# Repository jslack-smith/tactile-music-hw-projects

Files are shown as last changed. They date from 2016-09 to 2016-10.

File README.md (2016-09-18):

# tactile-music-hw-projects
Tactile Music is a project for an electrical engineering design course, ELEC3117, at UNSW.
This repo is for EAGLE project files.

How to use:
* clone this repo into your EAGLE projects folder

Notes:
* Use the DINA4_L (A4, landscape) frame on all sheets
* Use R-US_R0805 for resistors
* Use LEDCHIPLED_0805 for LED's

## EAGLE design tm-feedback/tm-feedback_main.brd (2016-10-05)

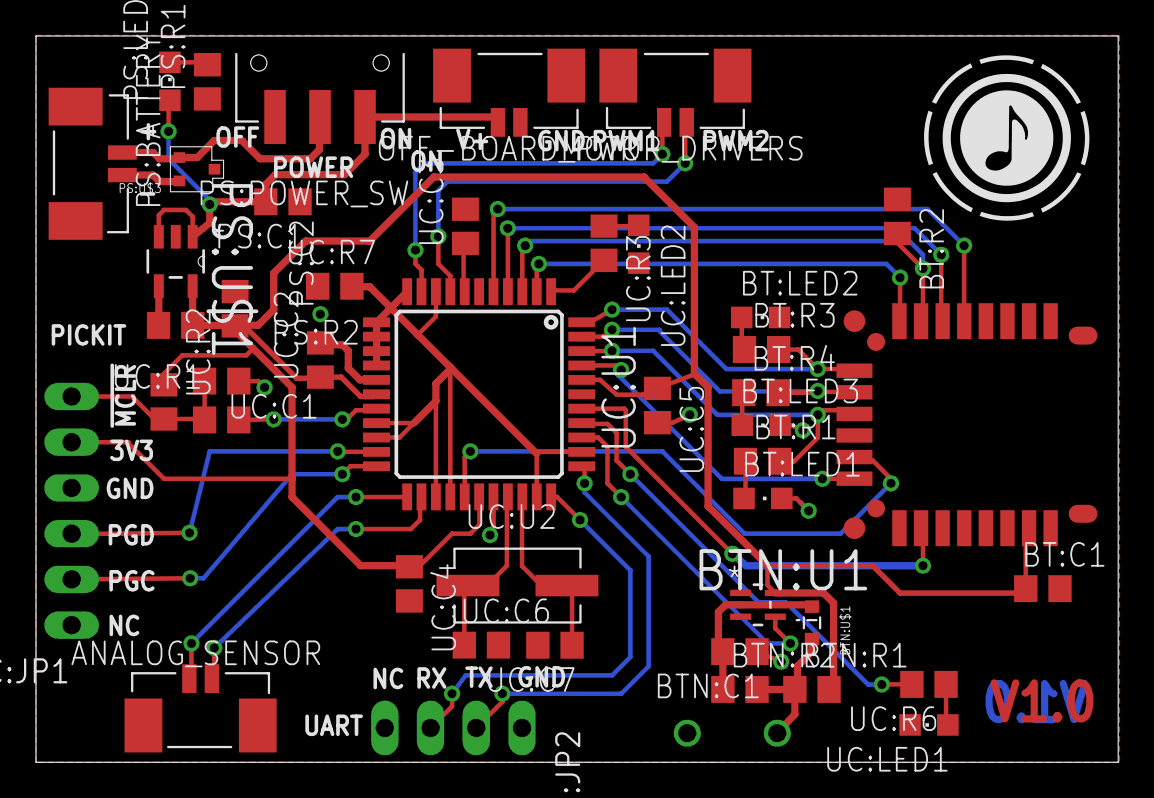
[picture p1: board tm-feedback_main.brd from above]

Board: 2 copper layers, 60.1 x 40.3 mm, 45 parts (1 on the bottom side), 41 nets.

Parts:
ANALOG_SENSOR: PICOBLADE
BT:C1: 4.7uF; C0805
BT:LED1: YELLOW; CHIPLED_0805
BT:LED2: RED; CHIPLED_0805
BT:LED3: GREEN; CHIPLED_0805
BT:R1, BT:R3, BT:R4: 53.6Ω; R0805
BT:R2: 10kΩ; R0805
BT:U$1: RN4020
BTN:C1: 1uF; C0805
BTN:PAIRING_SW: MC32881_TACTILE; THRU-TACTILE-BTN
BTN:R1: 33k; R0805
BTN:R2: 18k; R0805
BTN:U1: 74AUP1G17GW; SOT65P212X110-5N
BTN:U$1: DB2S308; SOD-523
MOTOR_DRIVERS: PICOBLADE
OFF-BOARD_PWR: PICOBLADE
PS:BATTERY: PICOBLADE
PS:C1, PS:C2: 10uF; C0805
PS:LED1: RED; CHIPLED_0805
PS:POWER_SW: JS102011SAQN
PS:R1: 53.6Ω; R0805
PS:R2: 10k; R0805
PS:U$1: MCP1824T-3302E/OT; SOT95P270X145-5N
PS:U$3: PMF370XN; SOT323(SC-70)
UC:C1: C0805
UC:C2, UC:C4, UC:C5: 0.1uF; C0805
UC:C3: 10uF; C0805
UC:C6, UC:C7: 27pF; C0805
UC:JP1: PICKIT; 1X06/90
UC:JP2: UART_PC; 1X04/90
UC:LED1, UC:LED2: GREEN; CHIPLED_0805
UC:R1: 330Ω; R0805
UC:R2, UC:R7: 10kΩ; R0805
UC:R3, UC:R6: 53.6Ω; R0805
UC:U1: DSPIC33EP512MC504; TQFP44
UC:U2: XTAL_ABLS7M2

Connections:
+3V3: BT:C1.1, BT:U$1.23, BTN:R1.2, BTN:U1.5, PS:C2.2, PS:R2.2, PS:U$1.5, UC:C2.1, UC:C4.1, UC:C5.1, UC:JP1.5, UC:R2.2, UC:U1.17, UC:U1.28, UC:U1.40
BT:N$6: BT:LED2.A, BT:R3.1
BT:N$7: BT:LED3.A, BT:R4.1
BT:N$8: BT:LED1.A, BT:R1.1
BTN:N$1: BTN:PAIRING_SW.P$2, BTN:R1.1, BTN:R2.2, BTN:U$1.2
BTN:N$2: BTN:C1.2, BTN:R2.1, BTN:U1.2, BTN:U$1.1
GND: BT:C1.2, BT:LED1.C, BT:LED2.C, BT:LED3.C, BT:R2.1, BT:U$1.1, BT:U$1.9, BT:U$1.16, BT:U$1.24, BTN:C1.1, BTN:PAIRING_SW.P$1, BTN:U1.3, OFF-BOARD_PWR.1, PS:C1.1, PS:C2.1, PS:R1.1, PS:U$1.2, PS:U$3.3, UC:C1.2, UC:C2.2, UC:C3.2, UC:C4.2, UC:C5.2, UC:C6.2, UC:C7.2, UC:JP1.4, UC:JP2.1, UC:LED1.C, UC:LED2.C, UC:R7.2, UC:U1.6, UC:U1.16, UC:U1.29, UC:U1.39
unnamed: BTN:U1.4, UC:U1.36
unnamed: BT:U$1.14, UC:U1.27
unnamed: OFF-BOARD_PWR.2, PS:C1.2, PS:LED1.A, PS:POWER_SW.1, PS:U$1.1, PS:U$1.3
unnamed: BT:U$1.18, UC:U1.38
unnamed: BT:U$1.5, UC:U1.5
unnamed: BT:U$1.6, UC:U1.4
unnamed: BT:U$1.15, UC:U1.41
unnamed: BT:R2.2, BT:U$1.7, UC:U1.3
unnamed: BT:U$1.8, UC:U1.2
unnamed: BT:R3.2, BT:U$1.10, UC:U1.44
unnamed: BT:R4.2, BT:U$1.11, UC:U1.43
unnamed: BT:R1.2, BT:U$1.12, UC:U1.42
unnamed: ANALOG_SENSOR.1, UC:U1.23
unnamed: ANALOG_SENSOR.2, UC:U1.24
PS:BATT_V+: PS:BATTERY.1, PS:POWER_SW.2, PS:U$3.1
PS:BATT_V-: PS:BATTERY.2, PS:U$3.2
PS:N$3: PS:LED1.C, PS:R1.2
PS:PWRGD: PS:R2.1, PS:U$1.4
PWM_1: MOTOR_DRIVERS.2, UC:U1.10
PWM_2: MOTOR_DRIVERS.1, UC:U1.8
UC:!MCLR: UC:C1.1, UC:JP1.6, UC:R1.1, UC:R2.1
UC:LED1: UC:R6.2, UC:U1.37
UC:LED2: UC:R3.2, UC:U1.1
UC:N$1: UC:R1.2, UC:U1.18
UC:N$3: UC:C3.1, UC:U1.7
UC:N$4: UC:LED2.A, UC:R3.1
UC:N$10: UC:LED1.A, UC:R6.1
UC:OSC1: UC:C6.1, UC:U1.30, UC:U2.1
UC:OSC2: UC:C7.1, UC:U1.31, UC:U2.2
UC:PGC: UC:JP1.2, UC:U1.22
UC:PGD: UC:JP1.3, UC:U1.21
UC:UART2_RX: UC:JP2.3, UC:U1.33
UC:UART2_TX: UC:JP2.2, UC:U1.34
UC:UNUSED: UC:R7.1, UC:U1.9, UC:U1.11, UC:U1.12, UC:U1.13, UC:U1.14, UC:U1.15, UC:U1.19, UC:U1.20, UC:U1.25, UC:U1.26, UC:U1.32, UC:U1.35

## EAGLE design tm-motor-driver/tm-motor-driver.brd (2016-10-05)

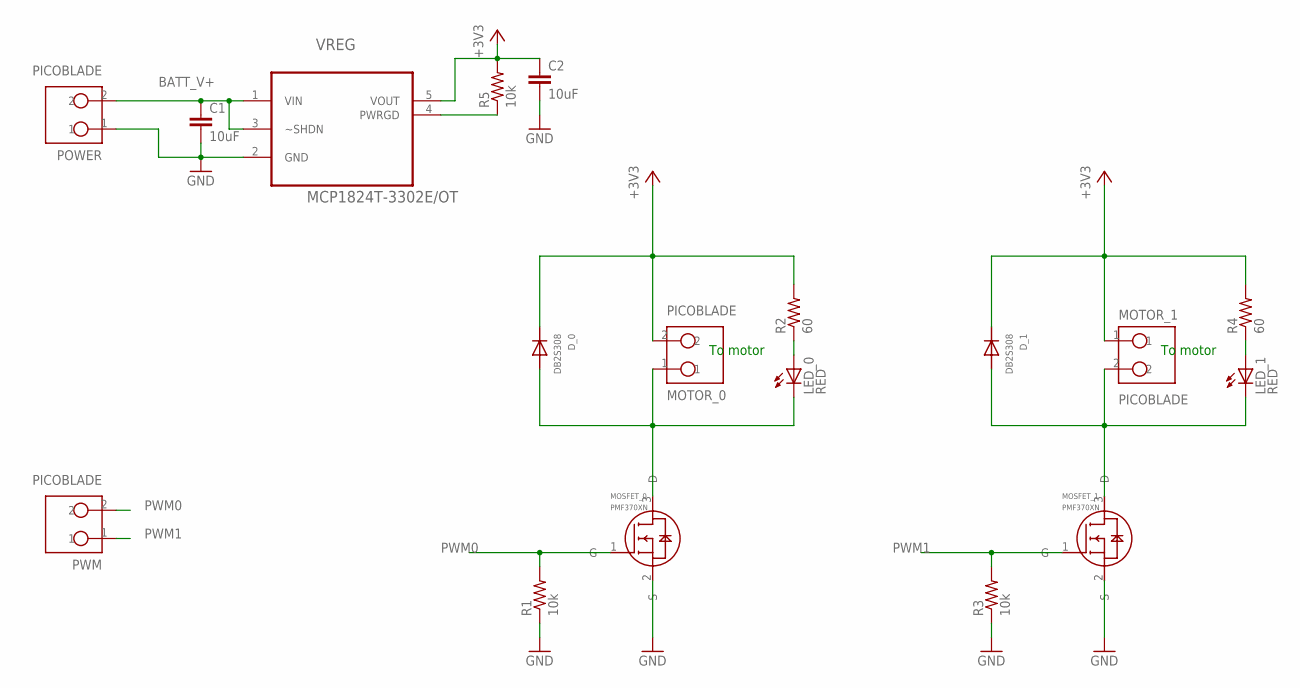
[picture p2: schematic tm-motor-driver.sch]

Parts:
C1, C2: 10uF; C0805
D_0, D_1: DB2S308; SOD-523
LED_0, LED_1: RED; CHIPLED_0805
MOSFET_0, MOSFET_1: PMF370XN; SOT323(SC-70)
MOTOR_0, MOTOR_1: PICOBLADE
POWER: PICOBLADE
PWM: PICOBLADE
R1, R3, R5: 10k; R0805
R2, R4: 60; R0805
VREG: MCP1824T-3302E/OT; SOT95P270X145-5N

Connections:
+3V3: C2.1, D_0.1 (CATHODE), D_1.1 (CATHODE), MOTOR_0.2, MOTOR_1.1, R2.2, R4.2, R5.2, VREG.5 (VOUT)
BATT_V+: C1.1, POWER.2, VREG.1 (VIN), VREG.3 (~SHDN)
GND: C1.2, C2.2, MOSFET_0.2 (S), MOSFET_1.2 (S), POWER.1, R1.1, R3.1, VREG.2 (GND)
unnamed: D_1.2 (ANODE), LED_1.C, MOSFET_1.3 (D), MOTOR_1.2
unnamed: D_0.2 (ANODE), LED_0.C, MOSFET_0.3 (D), MOTOR_0.1
unnamed: LED_0.A, R2.1
unnamed: LED_1.A, R4.1
unnamed: R5.1, VREG.4 (PWRGD)
PWM0: MOSFET_0.1 (G), PWM.2, R1.2
PWM1: MOSFET_1.1 (G), PWM.1, R3.2

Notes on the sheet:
To motor

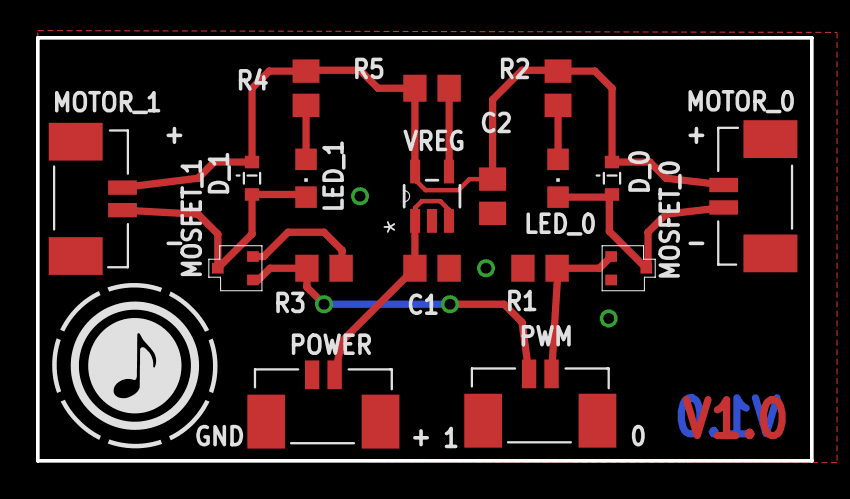
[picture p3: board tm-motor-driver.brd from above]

Board: 2 copper layers, 43.0 x 23.5 mm, 18 parts (0 on the bottom side), 10 nets.

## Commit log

2016-09-15 Create tm-feedback EAGLE project
    [tm-feedback_main.brd, tm-feedback_main.sch]
2016-09-17 Create some empty modules
    [tm-feedback_main.sch]
2016-09-17 Add note on which frame to use
2016-09-17 Create all modules (empty)
    [tm-feedback_main.sch]
2016-09-17 Add ports to modules (bluetooth, uC) not complete
    [tm-feedback_main.sch]
2016-09-17 Add some intermodule connections
    [tm-feedback_main.brd, tm-feedback_main.sch]
2016-09-18 Add note on which resistor device to use
2016-09-18 Add note on which LED device to use
2016-09-18 Add some components, complete motor driver
    [tm-feedback_main.brd, tm-feedback_main.sch]
2016-09-21 Add headers
    [tm-feedback_main.brd, tm-feedback_main.sch]
2016-09-21 Add some custom library components to schematics
    [tm-feedback_main.brd, tm-feedback_main.sch]
2016-09-22 Made a start on the bluetooth module
    [tm-feedback_main.brd, tm-feedback_main.sch]
2016-09-22 Completed Bluetooth Module
    [tm-feedback_main.brd, tm-feedback_main.sch]
2016-09-23 First version of motor driver schematic
    [tm-motor-driver.sch]
2016-09-23 Add R on power good
    [tm-motor-driver.brd, tm-motor-driver.sch]
2016-09-23 Add note about input cap size choice
    [tm-motor-driver.sch]
2016-09-23 Remove jumpers, rearrange LED and series resistor for easier layout
    [tm-motor-driver.brd, tm-motor-driver.sch]
2016-09-23 Change header to JST
    [tm-motor-driver.brd, tm-motor-driver.sch]
2016-09-23 Change MOTOR_0 JST connections to make PCB routing easier
    [tm-motor-driver.brd, tm-motor-driver.sch]
2016-09-24 Fixed simple schematic errors, and made some PCB fixes / enhancements
    [tm-motor-driver.brd, tm-motor-driver.sch]
2016-09-24 Fix LED_0 clearance error
    [tm-motor-driver.brd]
2016-09-24 Reduce board size
    [tm-motor-driver.brd]
2016-09-24 Move VREG name
    [tm-motor-driver.brd]
2016-09-24 Added value to bluetooth module decoupling cap
    [tm-feedback_main.brd, tm-feedback_main.sch]
2016-09-24 Generate gerber files
    [tm-motor-driver.brd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]
2016-09-24 Added dsPIC into microcontroller schematic
    [tm-feedback_main.brd, tm-feedback_main.sch]
2016-09-24 Regenerate gerber files
2016-09-24 Started on PIC schematic
    [tm-feedback_main.brd, tm-feedback_main.sch]
2016-09-24 Change PS, add button, remove MOTOR_DRIVER
    [tm-feedback_main.brd, tm-feedback_main.sch]
2016-09-24 Add power switch
    [tm-feedback_main.brd, tm-feedback_main.sch]
2016-09-24 Wired most of the board up. Currently have ERC issues.
    [tm-feedback_main.brd, tm-feedback_main.sch]
2016-09-25 Moved Bluetooth Module to rigth place
    [tm-feedback_main.brd]
2016-09-25 Rearrange power
    [tm-feedback_main.brd, tm-feedback_main.sch]
2016-09-25 Fixed and approved ERC errors
    [tm-feedback_main.brd, tm-feedback_main.sch]
2016-09-25 Replaced JST with picoblade
    [tm-feedback_main.brd, tm-feedback_main.sch, tm-motor-driver.brd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]
2016-09-25 Update PICOBLADE
    [tm-feedback_main.brd, tm-feedback_main.sch, tm-motor-driver.brd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]
2016-09-25 Add tactile
    [tm-feedback_main.brd, tm-feedback_main.sch]
2016-09-25 Resize board with new connectors
    [tm-motor-driver.brd]
2016-09-25 First attempt at board layout for main board
    [tm-feedback_main.brd, tm-feedback_main.sch]
2016-09-25 Arrange PS, rearrange PWM connections for easier layout, rename modules for shorter names (I will try do shorter commits\!)
    [tm-feedback_main.brd, tm-feedback_main.sch]
2016-09-25 Route power supply and button
    [tm-feedback_main.brd]
2016-09-25 More routing
    [tm-feedback_main.brd, tm-feedback_main.sch]
2016-09-25 More layout
    [tm-feedback_main.brd, tm-feedback_main.sch]
2016-09-25 Even more board layout
    [tm-feedback_main.brd, tm-feedback_main.sch]
2016-09-25 Finished board layout
    [tm-feedback_main.brd, tm-feedback_main.sch]
2016-09-26 Fix ground vias
    [tm-feedback_main.brd]
2016-09-26 Fix more ground vias
    [tm-feedback_main.brd, tm-feedback_main.sch]
2016-09-26 Replace PICKIT header with new header
    [tm-feedback_main.brd, tm-feedback_main.sch]
2016-09-26 Replace headers in schematic and board, no design rule errors
    [tm-feedback_main.brd, tm-feedback_main.sch]
2016-09-26 Add labels, icon
    [tm-feedback_main.brd, tm-feedback_main.sch]
2016-09-29 Changed LEDs to more accurate values
    [tm-feedback_main.brd, tm-feedback_main.sch]
2016-10-05 Fix power supply, shutdown should be connected to Vin not Vout
    [tm-feedback_main.brd, tm-feedback_main.sch, tm-motor-driver.brd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]
